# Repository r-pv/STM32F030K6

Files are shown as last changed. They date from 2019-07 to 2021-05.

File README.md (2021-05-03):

# rSTM32F030K6 ProMini

An ST development board based on the rSTM32F030K6T6/rSTM32F030K6 (Clock: 48MHz, flash: 32Kb, Ram:4Kb) MCU (LQFP-32) compatible with STM32Duino (Arduino).

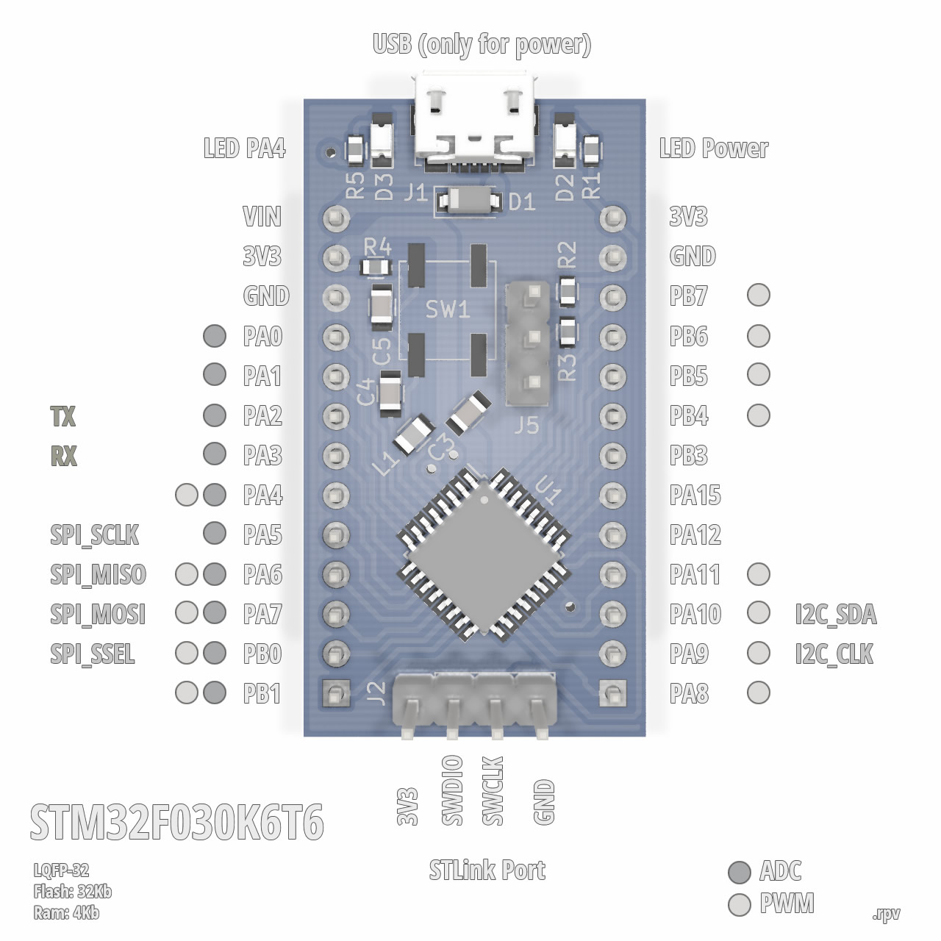
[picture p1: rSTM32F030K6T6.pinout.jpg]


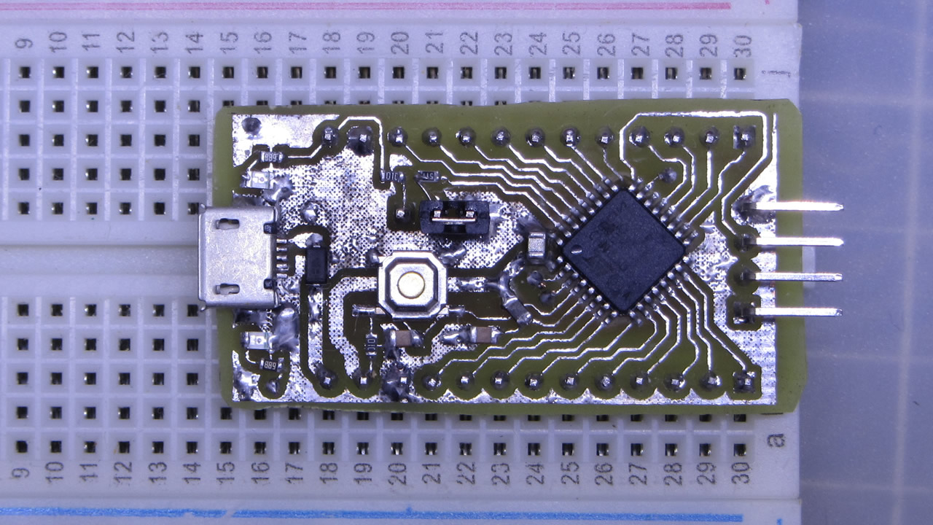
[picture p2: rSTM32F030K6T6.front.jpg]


## Install

**Update:** STCore v2.0 includes support for this MCU, if you're using STCore v2.0 you don't need to install anything.

- This requires the [STM32 core for arduino](https://github.com/stm32duino/Arduino_Core_STM32/), the ST original.
- I used this [guide to add the board](https://github.com/stm32duino/wiki/wiki/Add-a-new-variant-(board)), you can check it or continue with my suggestions to install the new board.
- Copy the **"DEMO_F030K6"** folder to the Arduino **"variants"** folder, in win7 is located at: **c:\Users\\<USERNAME\>\AppData\Local\Arduino15\packages\STM32\hardware\stm32\1.6.1\variants**
- Edit the **"boards.txt"** file, in win7 is located at a lever up than the "variants" folder, search for the **F030F4** board and add the lines to leave as I show you next:
```
# DEMO_F030F4 board
# Support: Serial1 (USART1 on PA3, PA2)
GenF0.menu.pnum.DEMO_F030F4=STM32F030F4 Demo board
GenF0.menu.pnum.DEMO_F030F4.upload.maximum_data_size=4096
GenF0.menu.pnum.DEMO_F030F4.upload.maximum_size=16384
GenF0.menu.pnum.DEMO_F030F4.build.mcu=cortex-m0
GenF0.menu.pnum.DEMO_F030F4.build.board=DEMO_F030F4
GenF0.menu.pnum.DEMO_F030F4.build.series=STM32F0xx
GenF0.menu.pnum.DEMO_F030F4.build.product_line=STM32F030x6
GenF0.menu.pnum.DEMO_F030F4.build.variant=DEMO_F030F4
GenF0.menu.pnum.DEMO_F030F4.build.cmsis_lib_gcc=arm_cortexM0l_math

# DEMO_F030K6 board
# Support: Serial1 (USART1 on PA3, PA2)
GenF0.menu.pnum.DEMO_F030K6=STM32F030K6 Demo board
GenF0.menu.pnum.DEMO_F030K6.upload.maximum_data_size=4096
GenF0.menu.pnum.DEMO_F030K6.upload.maximum_size=32768
GenF0.menu.pnum.DEMO_F030K6.build.mcu=cortex-m0
GenF0.menu.pnum.DEMO_F030K6.build.board=DEMO_F030K6
GenF0.menu.pnum.DEMO_F030K6.build.series=STM32F0xx
GenF0.menu.pnum.DEMO_F030K6.build.product_line=STM32F030x6
GenF0.menu.pnum.DEMO_F030K6.build.variant=DEMO_F030K6
GenF0.menu.pnum.DEMO_F030K6.build.cmsis_lib_gcc=arm_cortexM0l_math
```

## Files and Folders description

- **DEMO_F030K6** it's the variant board for the STM32 Arduino Core.
- **gerbers** it's the PCB gerbers.
- **rSTM32F030K6T6** it's the KiCAD 5.1.2 project.
- **Schematic.pdf** as in the name.

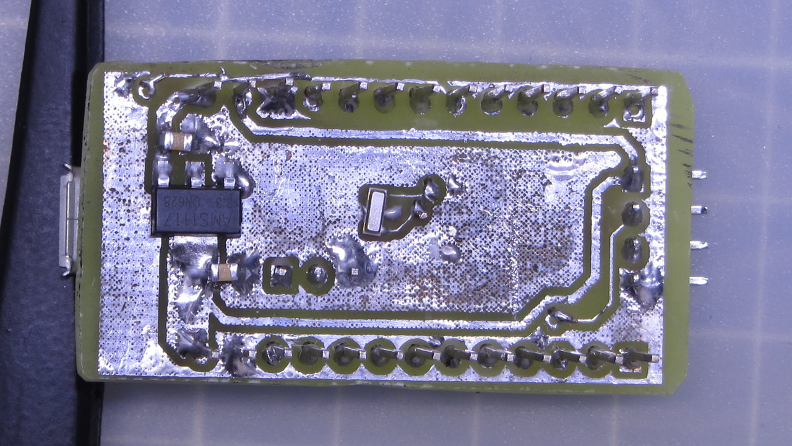
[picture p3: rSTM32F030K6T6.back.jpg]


## Running some tests

clip (https://www.youtube.com/watch?v=J8X1p-aLzaY)

clip (https://www.youtube.com/watch?v=zFgptjPR0z0)

## Reducing the size of your sketch

For some reason it seems that the sketchs for this platform gets way too fat (relative to standard arduino-atmel sketch sizes) and on some cases won't fit well on our board, a way to fit the sketchs to the flash/ram size that this board has it's to create a file **hal_conf_extra.h** on the sketch folder and disabling all features that weren't using:

```
#define HAL_ADC_MODULE_DISABLED
#define HAL_I2C_MODULE_DISABLED
#define HAL_RTC_MODULE_DISABLED
#define HAL_SPI_MODULE_DISABLED
#define HAL_TIM_MODULE_DISABLED
#define HAL_DAC_MODULE_DISABLED
#define HAL_EXTI_MODULE_DISABLED
#define HAL_ETH_MODULE_DISABLED
#define HAL_SD_MODULE_DISABLED
#define HAL_QSPI_MODULE_DISABLED
```
_(an arduino restart may be required on changes to this file)._

Also, if you aren't using the serial you cand disable it on the arduino menu:

**Board > U(S)ART Support > Disabled.**

## Notes

This it's the first board variant I made, so errors may occur.

[STM32Duino thread.](http://www.stm32duino.com/viewtopic.php?f=30&p=55201)

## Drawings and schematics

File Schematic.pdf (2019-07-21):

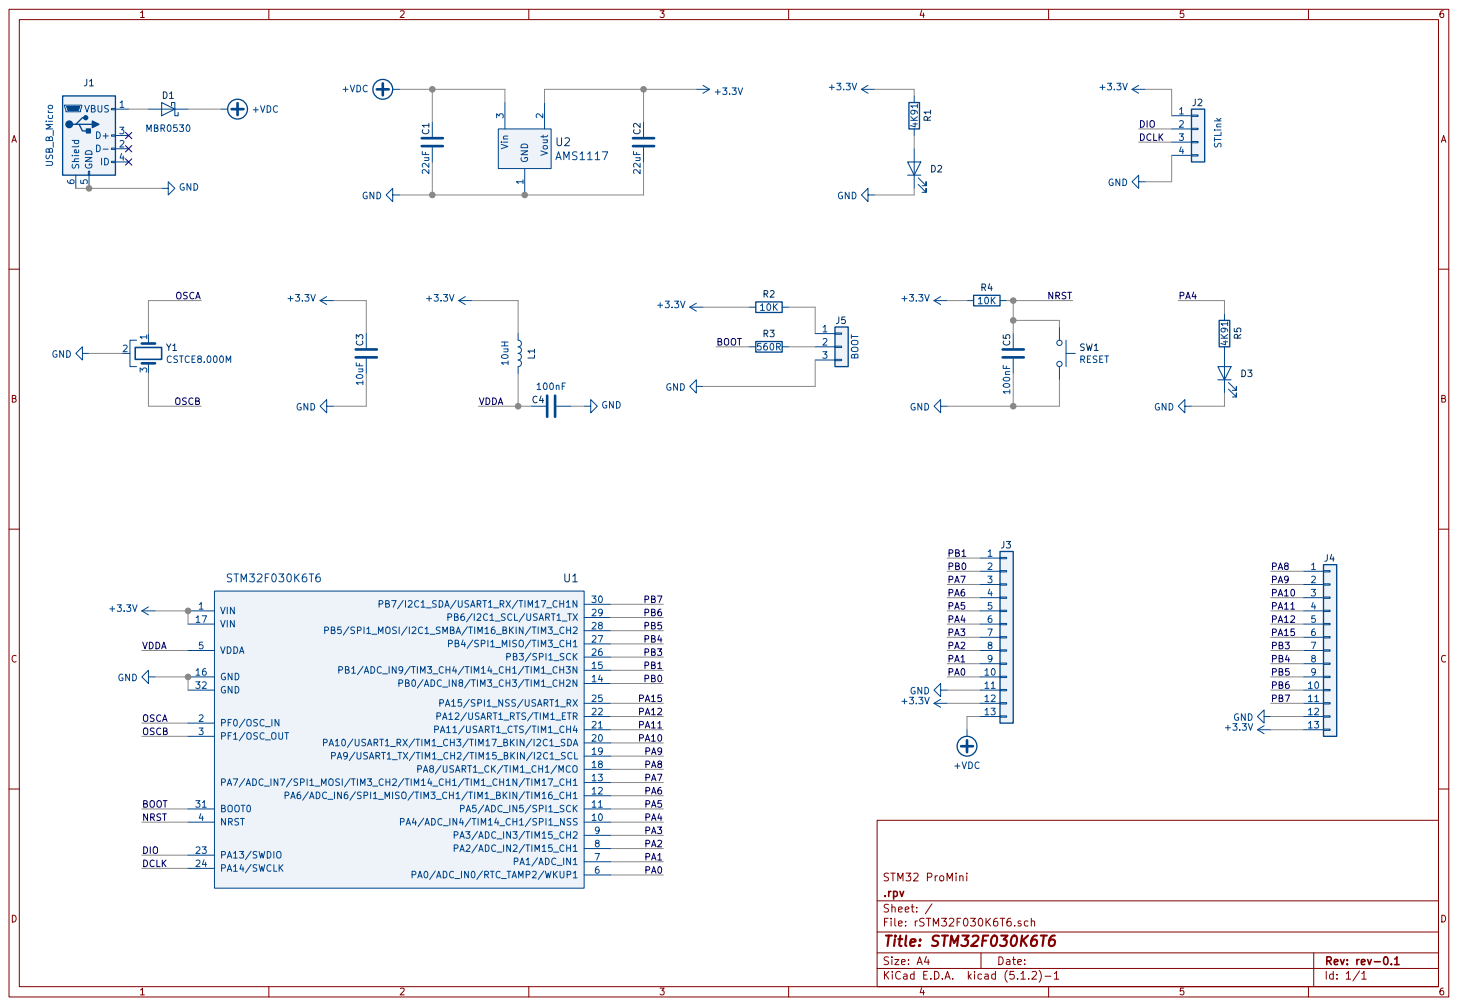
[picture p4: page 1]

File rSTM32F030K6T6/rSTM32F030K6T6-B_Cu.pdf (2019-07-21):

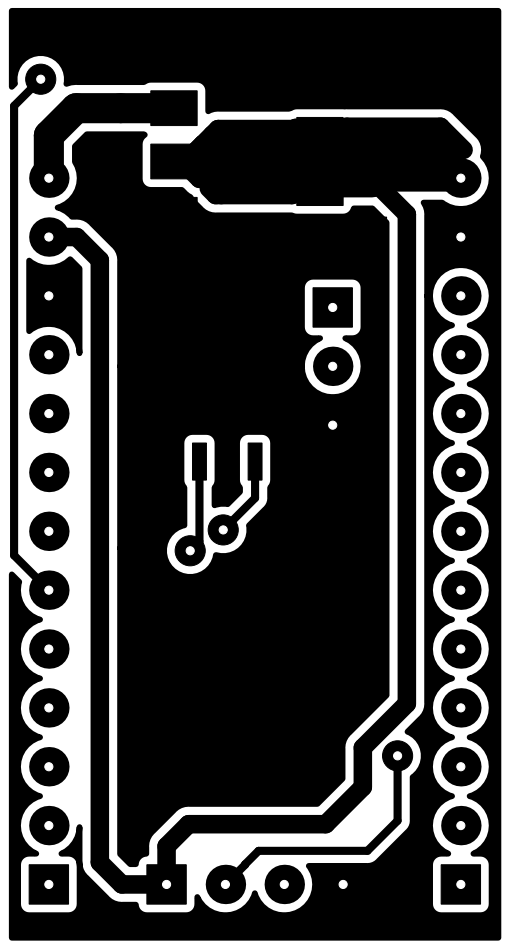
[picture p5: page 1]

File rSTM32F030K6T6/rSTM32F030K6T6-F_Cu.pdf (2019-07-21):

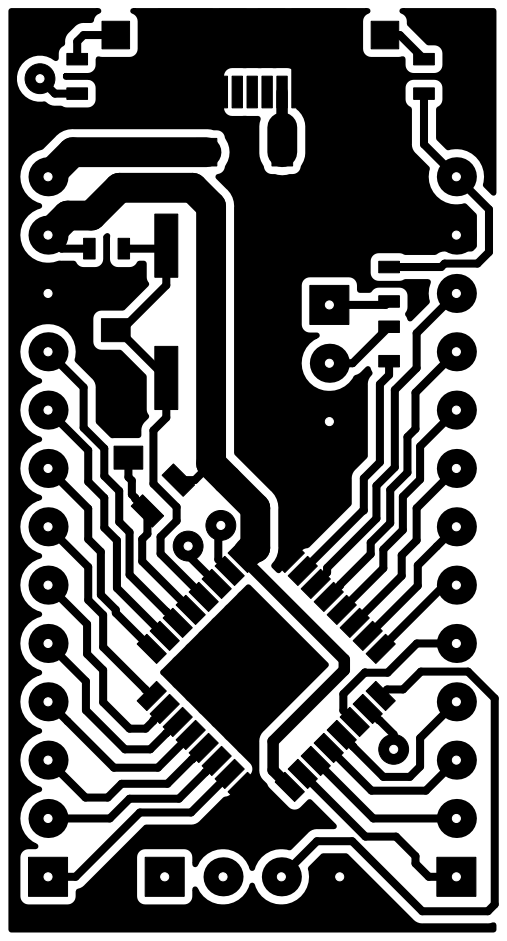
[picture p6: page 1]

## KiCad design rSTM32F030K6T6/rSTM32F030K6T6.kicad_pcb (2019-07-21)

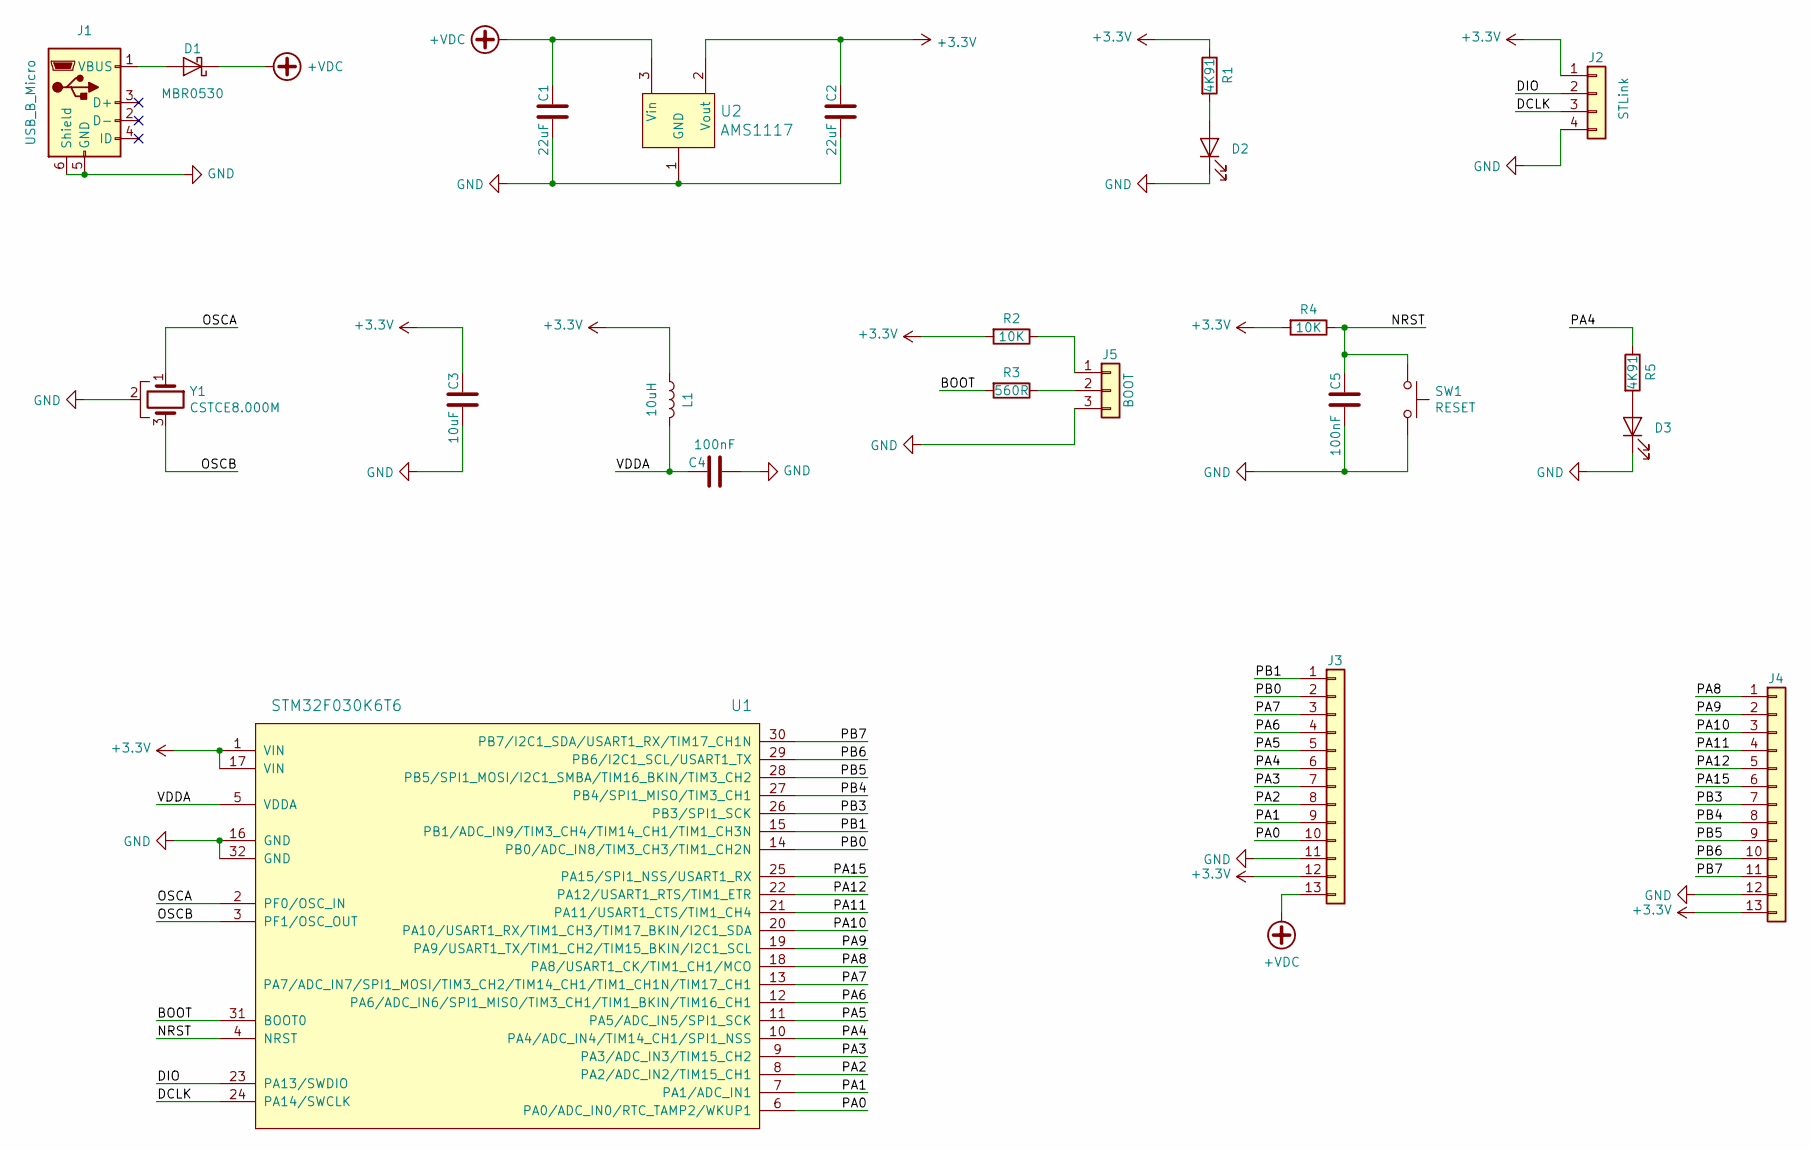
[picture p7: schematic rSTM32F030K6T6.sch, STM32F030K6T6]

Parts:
C1, C2: 22uF; C_0805
C3: 10uF; C_0805
C4, C5: 100nF; C_0805
D1: MBR0530; D_SOD-123
D2, D3: LED; LED_0805
J1: USB_B_Micro; USB_Micro-B_Molex_47346-0001
J2: STLink; Pin_Header_Straight_1x04_Pitch2.54mm
J3, J4: Pin_Header_Straight_1x13_Pitch2.54mm
J5: BOOT; Pin_Header_Straight_1x03_Pitch2.54mm
L1: 10uH; L_0805
R1, R5: 4K91; R_0603
R2, R4: 10K; R_0603
R3: 560R; R_0603
SW1: RESET; SW_SPST_EVPBF
U1: STM32F030K6T6; LQFP-32_7x7mm_Pitch0.8mm
U2: AMS1117; SOT-223-3_TabPin2
Y1: CSTCE8.000M; Crystal_CSTCE_3pin_3.2x1.3

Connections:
+3V3: C2.1, C3.1, J2.1, J3.12, J4.13, L1.1, R1.1, R2.2, R4.2, U1.1 (VIN), U1.17 (VIN), U2.2 (Vout)
+VDC: C1.1, D1.1 (K), J3.13, U2.3 (Vin)
/BOOT: R3.2, U1.31 (BOOT0)
/DCLK: J2.3, U1.24 (PA14/SWCLK)
/DIO: J2.2, U1.23 (PA13/SWDIO)
/NRST: C5.1, R4.1, SW1.1, U1.4 (NRST)
/OSCA: U1.2 (PF0/OSC_IN), Y1.1
/OSCB: U1.3 (PF1/OSC_OUT), Y1.3
/PA0: J3.10, U1.6 (PA0/ADC_IN0/RTC_TAMP2/WKUP1)
/PA1: J3.9, U1.7 (PA1/ADC_IN1)
/PA2: J3.8, U1.8 (PA2/ADC_IN2/TIM15_CH1)
/PA3: J3.7, U1.9 (PA3/ADC_IN3/TIM15_CH2)
/PA4: J3.6, R5.1, U1.10 (PA4/ADC_IN4/TIM14_CH1/SPI1_NSS)
/PA5: J3.5, U1.11 (PA5/ADC_IN5/SPI1_SCK)
/PA6: J3.4, U1.12 (PA6/ADC_IN6/SPI1_MISO/TIM3_CH1/TIM1_BKI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)
/PA7: J3.3, U1.13 (PA7/ADC_IN7/SPI1_MOSI/TIM3_CH2/TIM14_CH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)
/PA8: J4.1, U1.18 (PA8/USART1_CK/TIM1_CH1/MCO)
/PA9: J4.2, U1.19 (PA9/USART1_TX/TIM1_CH2/TIM15_BKIN/I2C1_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)
/PA10: J4.3, U1.20 (PA10/USART1_RX/TIM1_CH3/TIM17_BKIN/I2C1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)
/PA11: J4.4, U1.21 (PA11/USART1_CTS/TIM1_CH4)
/PA12: J4.5, U1.22 (PA12/USART1_RTS/TIM1_ETR)
/PA15: J4.6, U1.25 (PA15/SPI1_NSS/USART1_RX)
/PB0: J3.2, U1.14 (PB0/ADC_IN8/TIM3_CH3/TIM1_CH2N)
/PB1: J3.1, U1.15 (PB1/ADC_IN9/TIM3_CH4/TIM14_CH1/TIM1_CH3N)
/PB3: J4.7, U1.26 (PB3/SPI1_SCK)
/PB4: J4.8, U1.27 (PB4/SPI1_MISO/TIM3_CH1)
/PB5: J4.9, U1.28 (PB5/SPI1_MOSI/I2C1_SMBA/TIM16_BKIN/TIM3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)
/PB6: J4.10, U1.29 (PB6/I2C1_SCL/USART1_TX)
/PB7: J4.11, U1.30 (PB7/I2C1_SDA/USART1_RX/TIM17_CH1N)
/VDDA: C4.2, L1.2, U1.5 (VDDA)
GND: C1.2, C2.2, C3.2, C4.1, C5.2, D2.1 (K), D3.1 (K), J1.5 (GND), J1.6 (Shield), J2.4, J3.11, J4.12, J5.3, SW1.2, U1.16 (GND), U1.32 (GND), U2.1 (GND), Y1.2
unnamed: D1.2 (A), J1.1 (VBUS)
unnamed: D2.2 (A), R1.2
unnamed: D3.2 (A), R5.2
unnamed: J5.1, R2.1
unnamed: J5.2, R3.1

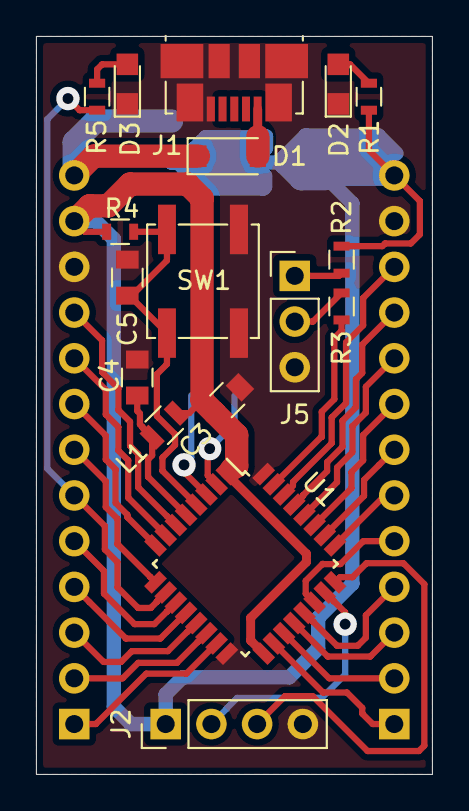
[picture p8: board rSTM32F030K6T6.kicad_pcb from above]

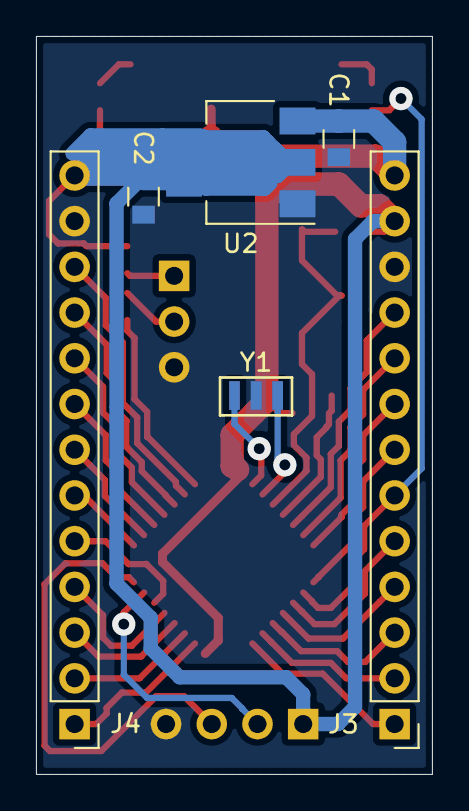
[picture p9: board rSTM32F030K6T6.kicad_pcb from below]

Board: 2 copper layers, 22.0 x 41.0 mm, 23 parts (6 on the bottom side), 36 nets.

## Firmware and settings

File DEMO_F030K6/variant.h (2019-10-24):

/*
 *******************************************************************************
 * Copyright (c) 2017, STMicroelectronics
 * All rights reserved.
 *
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
 * THIS SOFTWARE IS PROVIDED BY THE COPYRIGHT HOLDERS AND CONTRIBUTORS "AS IS"
 * AND ANY EXPRESS OR IMPLIED WARRANTIES, INCLUDING, BUT NOT LIMITED TO, THE
 * IMPLIED WARRANTIES OF MERCHANTABILITY AND FITNESS FOR A PARTICULAR PURPOSE ARE
 * DISCLAIMED. IN NO EVENT SHALL THE COPYRIGHT HOLDER OR CONTRIBUTORS BE LIABLE
 * FOR ANY DIRECT, INDIRECT, INCIDENTAL, SPECIAL, EXEMPLARY, OR CONSEQUENTIAL
 * DAMAGES (INCLUDING, BUT NOT LIMITED TO, PROCUREMENT OF SUBSTITUTE GOODS OR
 * SERVICES; LOSS OF USE, DATA, OR PROFITS; OR BUSINESS INTERRUPTION) HOWEVER
 * CAUSED AND ON ANY THEORY OF LIABILITY, WHETHER IN CONTRACT, STRICT LIABILITY,
 * OR TORT (INCLUDING NEGLIGENCE OR OTHERWISE) ARISING IN ANY WAY OUT OF THE USE
 * OF THIS SOFTWARE, EVEN IF ADVISED OF THE POSSIBILITY OF SUCH DAMAGE.
 *******************************************************************************
 */
#ifndef _VARIANT_ARDUINO_STM32_
#define _VARIANT_ARDUINO_STM32_

/*----------------------------------------------------------------------------
 *        Headers
 *----------------------------------------------------------------------------*/
#ifdef __cplusplus
extern "C"{
#endif // __cplusplus

/*----------------------------------------------------------------------------
 *        Pins
 *----------------------------------------------------------------------------*/
//.with.the.USB.on.the.bottom.and.left-to-right-to-top.naming;
// left.side
#define PA8    0
#define PA9    1
#define PA10   2
#define PA11   3
#define PA12   4
#define PA15   5
#define PB3    6
#define PB4    7
#define PB5    8
#define PB6    9
#define PB7    10
// Bottom.side
//USB
// Right.side
#define PA0    11
#define PA1    12
#define PA2    13
#define PA3    14
#define PA4    15
#define PA5    16
#define PA6    17
#define PA7    18
#define PB0    19
#define PB1    20
// top.stlink
#define PA13   21
#define PA14   22

// Define pin names to match digital pin number --> Dx
// It could be used with preprocessor tests (e.g. #if PXn == 3)
// so an enum will not work.
// !!!
// !!! Copy the digitalPin[] array from the variant.cpp
// !!! and remove all '_': PX_n --> PXn
// !!! For NC, comment the line to warn x pin number is NC
// !!! // x is NC
// !!! For duplicated pin name, comment the line to warn x pin number
// !!! is PXn which is already defined with y pin number
// !!! // x is PXn (y)
// !!! Ex:
// !!! ...
// !!! #define PA4  20 // A14
// !!! #define PB4  21
// !!! #define PB5  22
// !!! #define PB3  23
// !!! // 24 is PA4 (20)
// !!! // 25 is PB4 (21)
// !!! #define PA2  26 // A15
// !!! ...
//#define PXn x

// This must be a literal
// It is used with preprocessor tests (e.g. #if NUM_DIGITAL_PINS > 3)
// so an enum will not work.
#define NUM_DIGITAL_PINS        32

// Allow to define Arduino style alias for analog input pin number --> Ax
// All pins are digital, analog inputs are a subset of digital pins
// and must be contiguous to be able to loop on each value
// This must be a literal with a value less than or equal to MAX_ANALOG_INPUTS
// defined in pin_arduino.h
// It is used with preprocessor tests (e.g. #if NUM_ANALOG_INPUTS > 3)
// so an enum will not work.
// !!!
// !!! It must be aligned with the number of analog PinName
// !!! defined in digitalPin[] array in variant.cpp
// !!!
#define NUM_ANALOG_INPUTS       10
// Define digital pin number of the first analog input  (i.e. which digital pin is A0)
// First analog pin value (A0) must be greater than or equal to NUM_ANALOG_INPUTS
#define NUM_ANALOG_FIRST        11

// Below ADC, DAC and PWM definitions already done in the core
// Could be redefined here if needed
// ADC resolution is 12bits
//#define ADC_RESOLUTION          12
//#define DACC_RESOLUTION         12

// PWM resolution
//#define PWM_RESOLUTION          8
//#define PWM_FREQUENCY           1000
//#define PWM_MAX_DUTY_CYCLE      255

// On-board LED pin number
#define LED_BUILTIN             PA4
#define LED_GREEN               LED_BUILTIN

// On-board user button
#define USER_BTN                x

// Below SPI and I2C definitions already done in the core
// Could be redefined here if differs from the default one
// SPI Definitions
// SPI Definitions
#define PIN_SPI_SS              PB0
#define PIN_SPI_MOSI            PA7
#define PIN_SPI_MISO            PA6
#define PIN_SPI_SCK             PA5

// I2C Definitions
#define PIN_WIRE_SDA            PA10 // Default for Arduino connector compatibility
#define PIN_WIRE_SCL            PA9  // Default for Arduino connector compatibility

// Timer Definitions
// Do not use timer used by PWM pins when possible. See PinMap_PWM.
#define TIMER_TONE              TIM17

// Do not use basic timer: OC is required
#define TIMER_SERVO             TIM16  //TODO: advanced-control timers don't work

// UART Definitions
#define SERIAL_UART_INSTANCE    1
// Default pin used for 'Serial' instance
// Mandatory for Firmata
#define PIN_SERIAL_RX           PA3
#define PIN_SERIAL_TX           PA2

// UART Definitions
// Define here Serial instance number to map on Serial generic name
//#define SERIAL_UART_INSTANCE    x //ex: 2 for Serial2 (USART2)
// DEBUG_UART could be redefined to print on another instance than 'Serial'
//#define DEBUG_UART              ((USART_TypeDef *) U(S)ARTX) // ex: USART3
// DEBUG_UART baudrate, default: 9600 if not defined
//#define DEBUG_UART_BAUDRATE     x
// DEBUG_UART Tx pin name, default: the first one found in PinMap_UART_TX for DEBUG_UART
//#define DEBUG_PINNAME_TX        PX_n // PinName used for TX


// Optional PIN_SERIALn_RX and PIN_SERIALn_TX where 'n' is the U(S)ART number
// Used when user instanciate a hardware Serial using its peripheral name.
// Example: HardwareSerial mySerial(USART3);
// will use PIN_SERIAL3_RX and PIN_SERIAL3_TX if defined.
//#define PIN_SERIALn_RX          x // For U(S)ARTn RX
//#define PIN_SERIALn_TX          x // For U(S)ARTn TX
//#define PIN_SERIALLP1_RX        x // For LPUART1 RX
//#define PIN_SERIALLP1_TX        x // For LPUART1 TX

// SD card slot Definitions
// SD detect signal can be defined if required
//#define SD_DETECT_PIN           x
// SD Read/Write timeout, default value defined in STM32SD library
//#define SD_DATATIMEOUT          x

#ifdef __cplusplus
} // extern "C"
#endif
/*----------------------------------------------------------------------------
 *        Arduino objects - C++ only
 *----------------------------------------------------------------------------*/
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

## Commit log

2019-07-23 Added I2C and SPI pins
2019-07-24 Changes to work with 1.6.1 Core
    When I made this variant I was using 1.5 STM32 Core, now I've upgraded to 1.6.1 and the variant didn't work anymore so changes were needed.
    [variant.h]
2019-09-23 Pinout update: added ADC and PWM pins.
2019-10-24 Fixed a bug with the analogs.
    Fixed a mistake I made.
    [variant.h]
